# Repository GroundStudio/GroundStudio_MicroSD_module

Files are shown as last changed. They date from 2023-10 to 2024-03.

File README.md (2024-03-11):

GroundStudio microSD module 
====================================
microSD module REV0 2

Get it from [ardushop.ro](https://ardushop.ro/ro/home/2514-modul-microsd-groundstudio.html)

Explore all the GroundStudio products at [GroundStudio.ro](https://groundstudio.ro/)

Description
-------------------
MicroSD adapter module that can be used to connect a microSD card to your project.

Contents
-------------------

* [/Documentation](https://github.com/GroundStudio/GroundStudio_MicroSD_module/tree/main/Documentation) -- Contains documentation written during creation of this repository, with readme.md index of its own!
* [/Firmware](https://github.com/GroundStudio/GroundStudio_MicroSD_module/tree/main/Firmware) -- Firmware (bootloaders, etc)
* [/Hardware](https://github.com/GroundStudio/GroundStudio_MicroSD_module/tree/main/Hardware) -- Schematics, layout.
* [/Libraries](https://github.com/GroundStudio/GroundStudio_MicroSD_module/tree/main/Libraries) -- Arduino/CircuitPython libraries. 
* [/Tools](https://github.com/GroundStudio/GroundStudio_MicroSD_module/tree/main) -- Tools needed for compiling, uploading bootloader, etc.

Versions
-------------------
*(Not all tags shown)*
* [V0.2] Initial version

License
-------------------

This is released under the [Attribution-ShareAlike 4.0 International (CC BY-SA 4.0)](https://creativecommons.org/licenses/by-sa/4.0/) license. 
**You are welcome to use this for commercial purposes.**

Please consider contributing back to this project or others to help the open-source hardware community continue to thrive and grow! 

Certifications:

[Open Source Hardware Association](https://certification.oshwa.org/ro000013.html)   
   
certification-mark-RO000013-wide (https://certification.oshwa.org/ro000013.html)

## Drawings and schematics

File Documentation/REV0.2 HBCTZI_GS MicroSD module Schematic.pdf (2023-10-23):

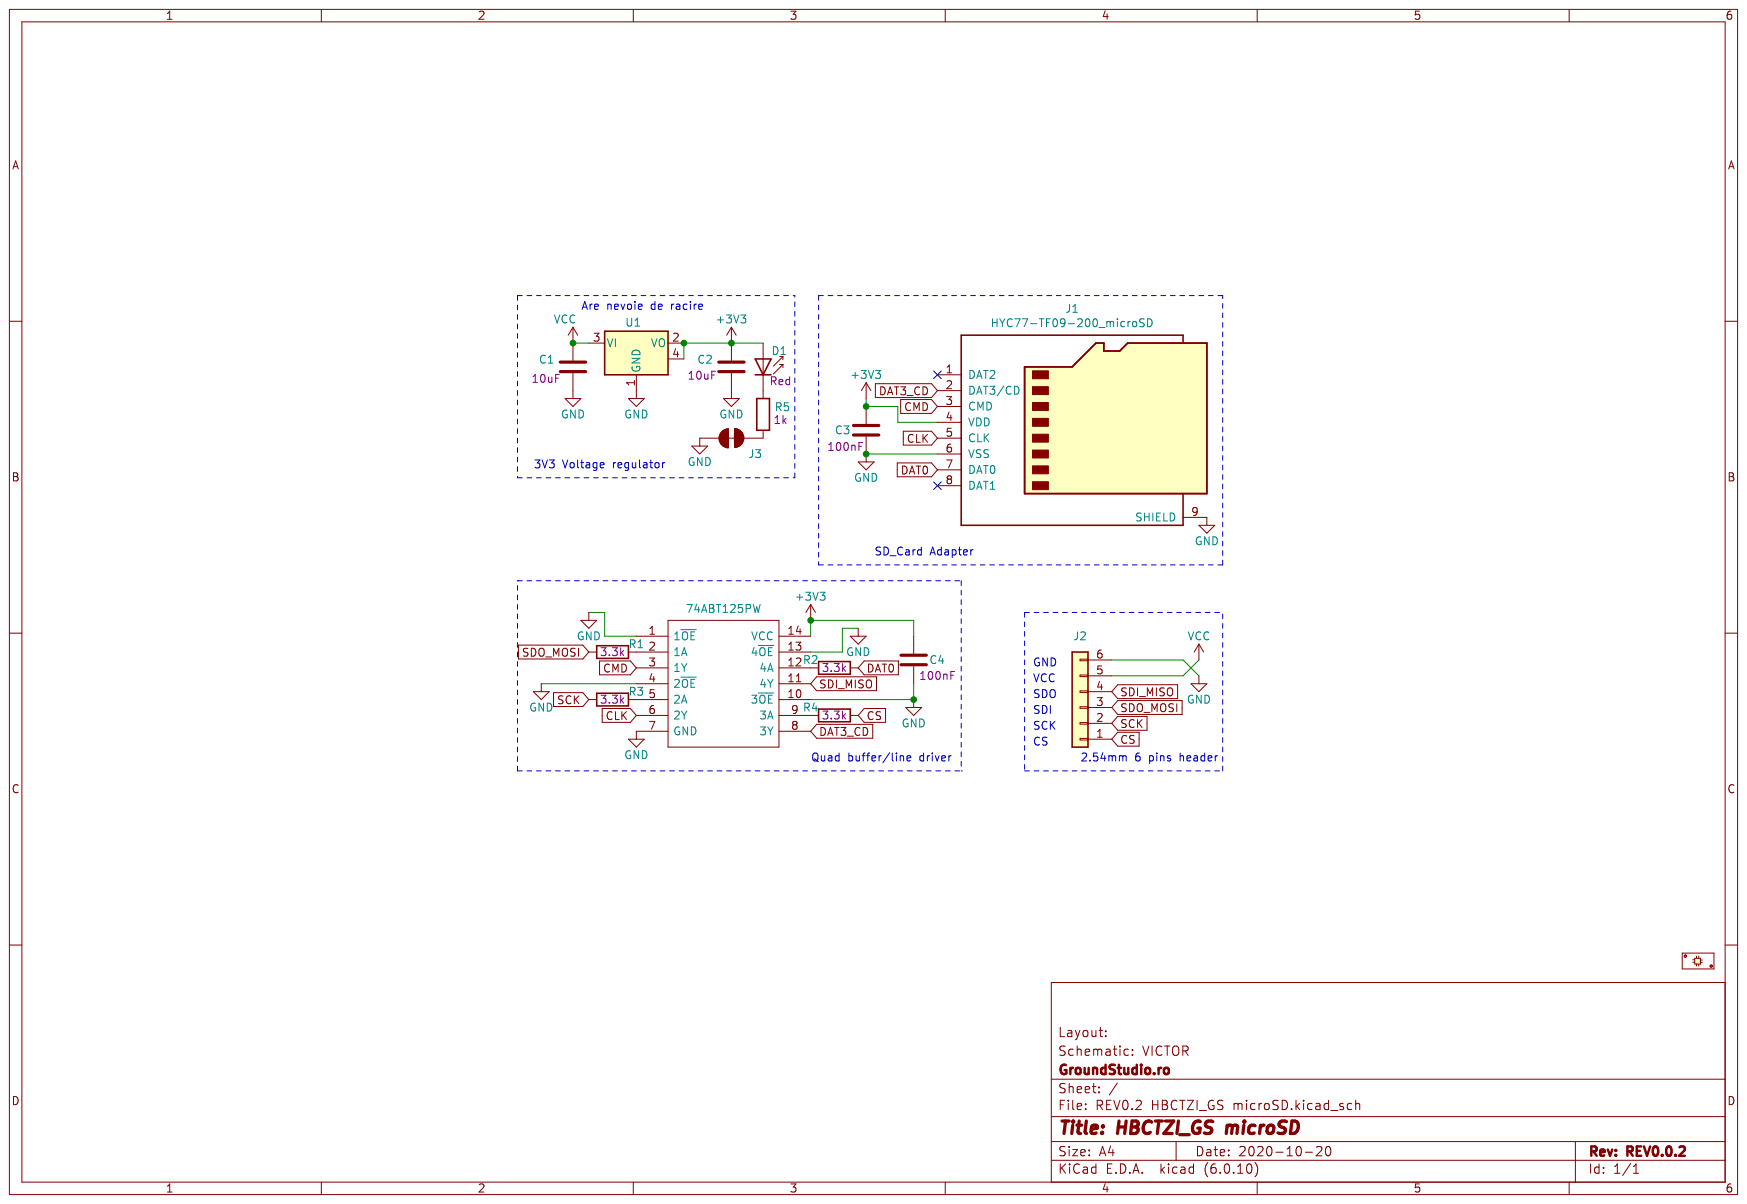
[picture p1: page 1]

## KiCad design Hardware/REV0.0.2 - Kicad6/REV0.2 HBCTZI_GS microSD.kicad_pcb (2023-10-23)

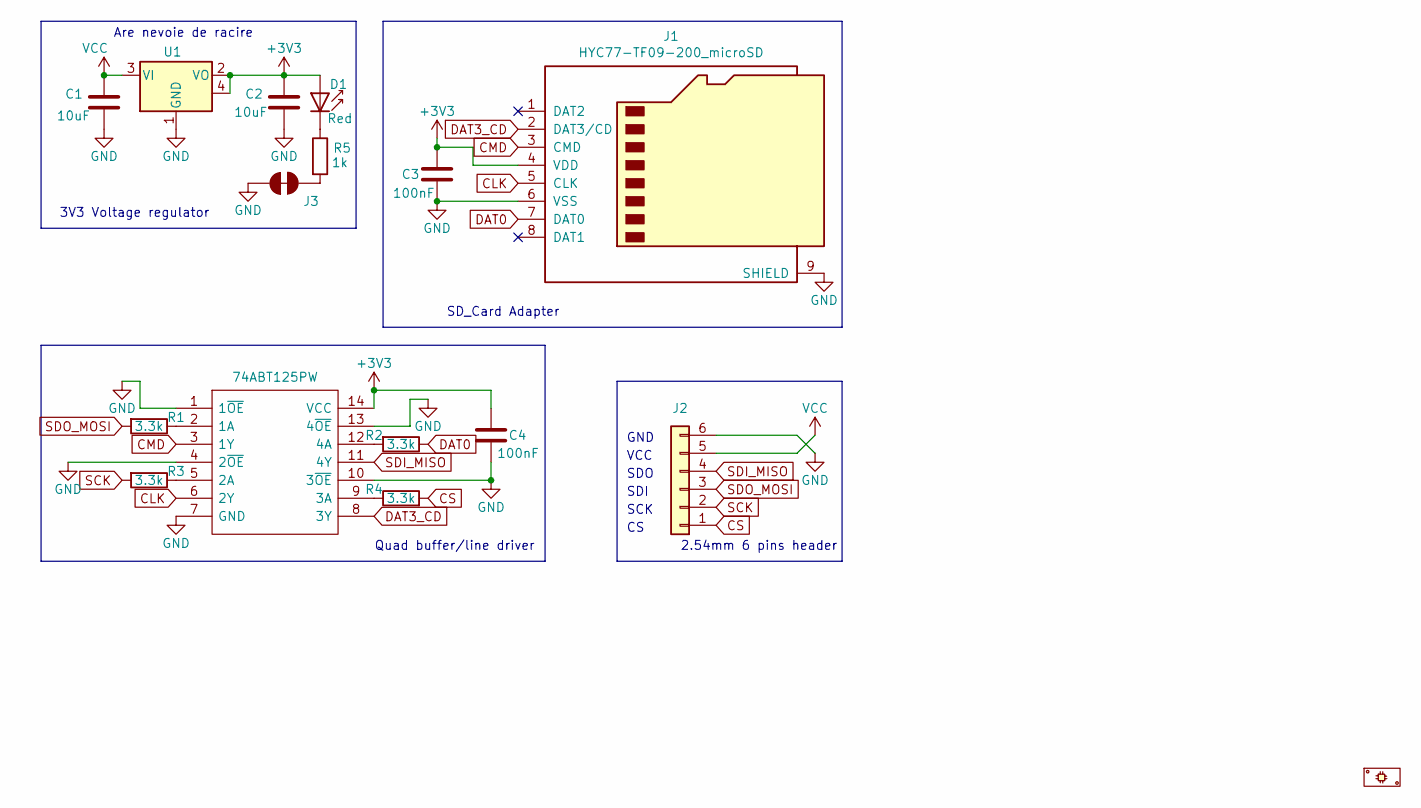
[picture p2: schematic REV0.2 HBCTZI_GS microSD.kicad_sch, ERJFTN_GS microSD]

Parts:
C1, C2: C_0402_10uF_10V; C_0402_1005Metric; MPN LDK105CBJ106MVLF; LCSC C386033
C3, C4: C_0402_100nF_10V; C_0402_1005Metric; MPN 0402B104K100CT; LCSC C387941
D1: LED_0402_RED; LED_0402_1005Metric; MPN TZ-P2-0402RTIA1-0.45T; LCSC C779449
IC1: 74ABT125PW; SOT402-1; MPN 74ABT125PW,118; LCSC C458207
J1: HYC77-TF09-200_microSD; HYC77-TF09-200; MPN HYC77-TF09-200; LCSC C341092
J2: Conn_01x06 Male Right Angle; PinHeader_1x06_P2.54mm_Vertical_Male; MPN C56816; LCSC C56816
J3: PWR LED DISABLE; SolderJumper_NC
P1: PCB; MPN HBCTZI_GS_PCB
R1, R2, R3, R4: R_0402_3.3k; R_0402_1005Metric; MPN RC-02W3301FT; LCSC C310224
R5: R_0402_1k; R_0402_1005Metric; MPN RC-02W1001FT; LCSC C226166
U1: SOT-223 AMS1117-3.3; SOT-223; MPN AMS1117-3.3; LCSC C347222

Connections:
+3V3: C2.2, C3.1, C4.1, D1.2 (A), IC1.14 (VCC), J1.4 (VDD), U1.2 (VO), U1.4
CLK: IC1.6 (2Y), J1.5 (CLK)
CMD: IC1.3 (1Y), J1.3 (CMD)
CS: J2.1, R4.2
DAT0: J1.7 (DAT0), R2.1
DAT3_CD: IC1.8 (3Y), J1.2 (DAT3/CD)
GND: C1.1, C2.1, C3.2, C4.2, IC1.1 (1~OE), IC1.4 (2~OE), IC1.7 (GND), IC1.10 (3~OE), IC1.13 (4~OE), J1.6 (VSS), J1.9 (SHIELD), J2.6, J3.2, U1.1 (GND)
unnamed: D1.1 (K), R5.1
unnamed: IC1.2 (1A), R1.1
unnamed: IC1.5 (2A), R3.1
unnamed: IC1.9 (3A), R4.1
unnamed: IC1.12 (4A), R2.2
unnamed: J3.1, R5.2
SCK: J2.2, R3.2
SDI_MISO: IC1.11 (4Y), J2.4
SDO_MOSI: J2.3, R1.2
VCC: C1.2, J2.5, U1.3 (VI)

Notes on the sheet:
Are nevoie de racire
GND
2.54mm 6 pins header
SCK
Quad buffer/line driver
3V3 Voltage regulator
VCC
SDI
SD_Card Adapter
SDO

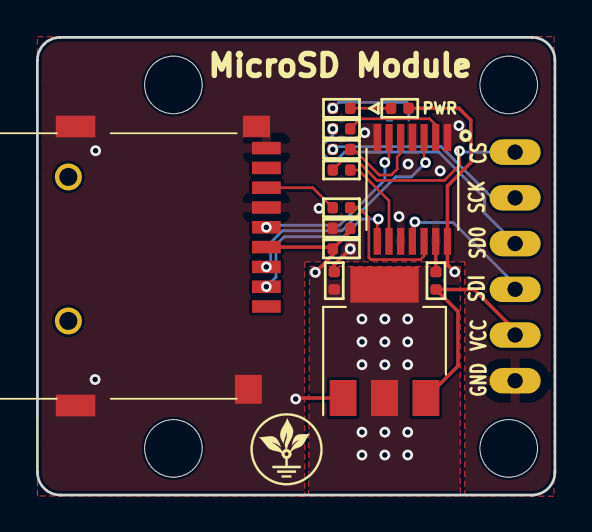
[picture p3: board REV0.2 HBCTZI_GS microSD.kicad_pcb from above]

Board: 2 copper layers, 28.8 x 25.4 mm, 15 parts (1 on the bottom side), 17 nets.
